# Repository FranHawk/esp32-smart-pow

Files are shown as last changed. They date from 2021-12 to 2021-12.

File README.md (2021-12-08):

# 前言

本文的目的是为了给将要制作的ESP32手环做技术储备

准备学习下ESP32，还有嵌入式GUI框架LVGL，通过做几个小项目练手是不错的选择，最终目标是做一个ESP32的手环

做一个ESP32手环任务量还是比较大的，涉及到很多新技术，我认为步子不能迈的太大容易翻车，决定先做一个ESP32的智能花盆

# 开源链接

**20211205 所有软硬件设计制作均已完成 资料开源至github**
**后续有时间还会发布一些小教程，可以在我的csdn上找到**

代码和外壳3D打印文件链接

[https://github.com/FranHawk/esp32-smart-pow](https://github.com/FranHawk/esp32-smart-pow)

GITHUB仓库结构
0.doc 相关文档
1.hardware pcb和3D打印所需资料
2.software  代码工程，有两个版本，gui版本可烧进任意ESP32或ESP32开发板，接屏幕和键盘即可，esp32-smart-pow为完成代码工程
3.simulator 存放lvgl的pc模拟器，用vs2019打开

PCB文件链接

[https://oshwhub.com/FranHawk/green-esp32/](https://oshwhub.com/FranHawk/green-esp32/)

视频演示链接

https://www.bilibili.com/video/BV11P4y137k2/

博客文档

https://blog.csdn.net/weixin_42487906/article/details/121779926

# 制作材料

元器件根据pcb工程里带的bom表买就可以了
pcb板嘉立创生产
电池买3.7V锂电池，容量随意
无线充电模块链接：https://item.taobao.com/item.htm?spm=a1z09.2.0.0.1bdb2e8dDijOkh&id=626465407103&_u=835dsdvlb35a
屏幕链接：https://item.taobao.com/item.htm?spm=a1z09.2.0.0.1bdb2e8dDijOkh&id=652101077844&_u=835dsdvl181e

外壳找淘宝3D打印

总成本大概100元左右，制作需要一些编程基础和网络信息搜索能力

## 开发平台

1.vs code+platformio ESP32开发

2.vs2019 lvgl模拟器 GUI界面设计与仿真

3.solidworks 2020 外壳设计

4.立创eda pcb设计

基本功能均已实现，还没发现更过BUG，如视频所示，但是软硬件还有需要进一步完善的地方，最近比较忙，等过了12月（202112）再进一步完善

# 功能

- 时间天气实时更新并显示
- 课程表，显示一周内的课程
- 电脑性能显示，通过局域网获取所使用的电脑当前的CPU内存等占用情况
- WIFI配网
- 亮度调节
- 蓝牙键盘，可作为一个蓝牙键盘控制电脑音量，ppt翻页，换歌等功能

# 功能展示



可以使用任意兼容QI标准的无线充电底座为其充电，市面上的充电底座几乎都可以



主界面显示天气时间温湿度，并且有利用lvgl8.1的gif解码器，有动图效果



天气界面



课程表界面



电脑性能监控界面



WIFI配网界面(功能和界面有待完善)



亮度调节界面



蓝牙键盘界面

**界面间通过一个滚动菜单选择**，可以使用模拟器模拟界面

下面是项目之初(20210920)写的需求分析和设计文档

# 需求分析

智能花盆所需要实现的功能如下：

- 基本花盆的功能：下端有透气孔，可以承载一株多肉植物，形状：长宽65mm正方形，高度根据实际情况调整的白色花盆，尽量保证外形的美观
- 带锂电池，无线充电模块，可以通过type-c口或者无线充电口为电池充电，同时为花盆供电。在无外部电源的时候，可以通过电池为花盆供电
- 板载USB转串口芯片，便于烧写代码
- 板载SD卡插槽，用户可将信息文件放入SD卡，ESP32可以读取
- ESP32 通过wifi功能，通过网络获取天气，时间等信息，通过局域网获取电脑性能等信息，后期可考虑加入wifi配网功能
- 通过一块1.54寸 240*240分辨率显示信息，信息如下，每一行代表一个页面
  	1. 当天时间和当天基本天气信息显示光照信息，检测当前是否充电，带**罗小黑动画效**果，通过晃动花盆可以切换动画效果
       2. 三天基本天气信息
       3. 电脑性能，内存占用等信息
       4. 课程表，显示当天课程
       5. 课程表，显示明天课程
       6. 显示当前植物信息

# 技术分析

- 首先硬件方面需要原理图PCB绘制和制作3D打印外壳技术，原理图PCB绘制采用立创EDA，外壳3D建模采用SW2020，去淘宝找厂家3D打印外壳 

  技能掌握情况：基本掌握

- 软件方面采用基于arduino的ESP32+LVGL框架，学习ESP32+LVGL基本使用，同时需要学习并移植XTRACK的页面生命周期管理API，根据需求分析需要掌握技术：LVGL移植到ESP32，ESP32连接到网络获取天气等信息，ESP32获取MPU6050数据，ESP32获取光敏电阻数据，LVGL文件系统移植，通过文件系统获取SD卡中信息，LVGL显示中文显示图片...

  20211002 基本掌握

## 任务细分

- 原理图和PCB绘制，投板制版并测试

  20210903 完成原理图和PCB绘制，已经投板，还未进入焊接阶段

  20210910 所有原件均到货，完成PCB制作，并完成测试，CH340不应该用5V供电，MPU6050少接一个电容工作不正常，其他部分工作正常，排线接口位置别扭，现有板子暂时能用，但是还是要再投一版

  20210915 新版本pcb投板并制作完成，测试完毕

  **已完成**

- 外壳设计与制作

  20210911 完成外壳设计工作

  20211120 完成外壳3D打印

  **已完成**

- 无线充电底座购买和无线充电模块测试

  20210910 无线充电底座到货，现有无线接收模块谐振频率不对，电压达不到5V，准备购买兼容QI协议的无线接收模块
  20211110 无线接收模块测试完毕
  **已达成**

- LVGL移植到ESP32

  20210817 完成LVGL移植

  **已达成**

- ESP32连接网络，获取天气，时间信息

  20210829 实现通过网络获取天气信息

  20210911 实现通过网络获取时间信息

  **已达成**

- ESP32连接网络，获取电脑性能信息

  20210825 实现通过网络获取电脑性能信息

  **已达成**

- ESP32获取MPU6050和光敏电阻的数据

  20210823 完成MPU6050数据获取

- ESP32上SD卡操作与LVGL文件系统移植

  20210830 完成SD卡操作与LVGL文件系统移植

  **已达成**

- LVGL中文和图片显示

  20210906 完成LVGL中文和图片显示

  **已达成**

- LVGL的PC模拟器使用

  20210906 初步完成LVGL的PC模拟器使用

  **已达成**

- LVGL移植XTRACK的页面生命周期管理API

  2021821 完成页面生命周期管理API学习，还未完成移植

  20210910 完成PC模拟器上菜单选择界面UI设计，发现XTRACK的页面生命周期管理暂时还用不到，先用纯LVGL开发

  **已达成**

- LVGL的PC模拟器设计UI交互页面

  20210910 完成PC模拟器上菜单选择界面UI设计，接下来完成子页面的设计

  20211120 完成所有子页面设计

  **已达成**

- UI交互页面移植到ESP32上，系统联调

  20211125 完成

  **已达成**

- ESP32上LVGL按键输入功能移植

  20210907 完成ESP32上LVGL按键输入功能移植

  **已达成**

# 硬件架构设计



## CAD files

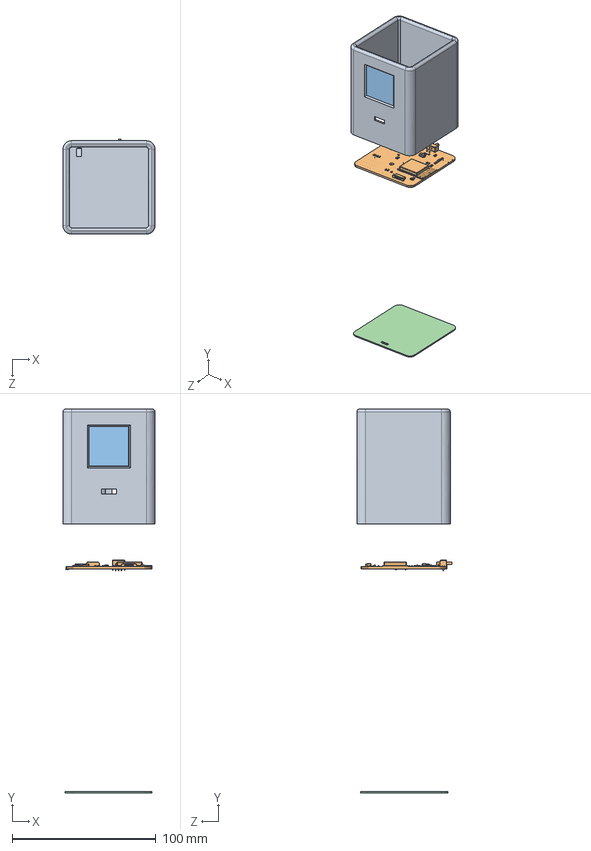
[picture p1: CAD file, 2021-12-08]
1.hardware/外壳文件/asm.SLDASM
64.0 x 266.8 x 66.3 mm
3D_PCB_PCB_green-esp32_2021-09-11_2021-09-11
1.54tft
bottom

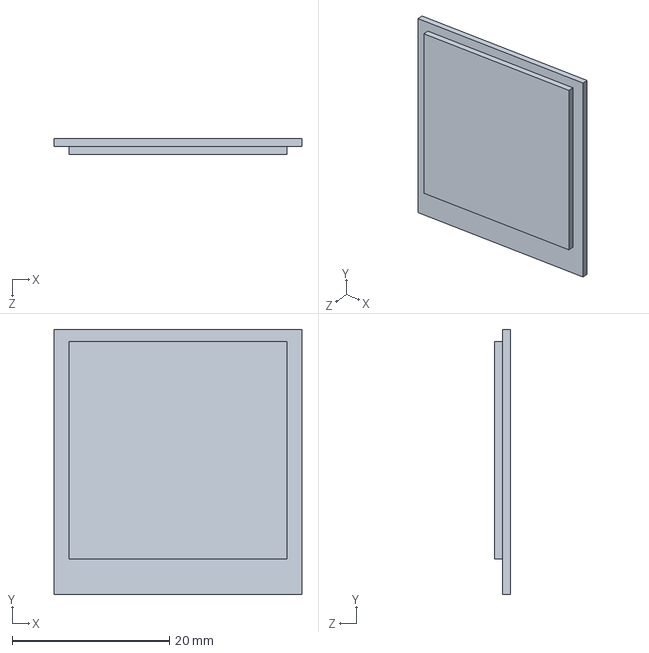
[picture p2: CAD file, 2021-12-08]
1.hardware/外壳文件/1.54tft.SLDPRT
31.5 x 33.7 x 2.00 mm

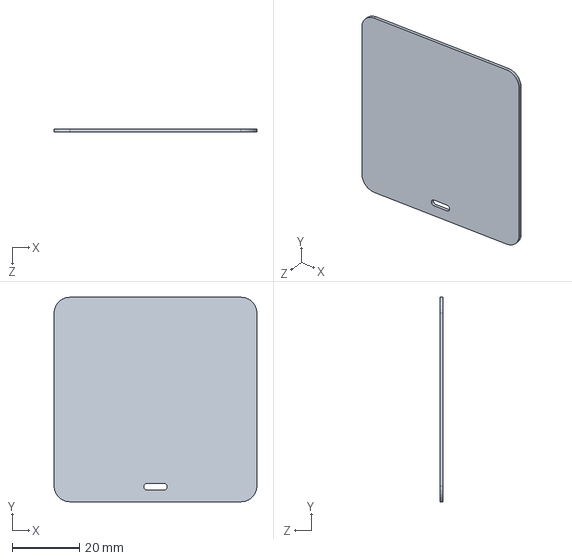
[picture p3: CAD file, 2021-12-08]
1.hardware/外壳文件/bottom.SLDPRT
60.5 x 61.0 x 1.00 mm

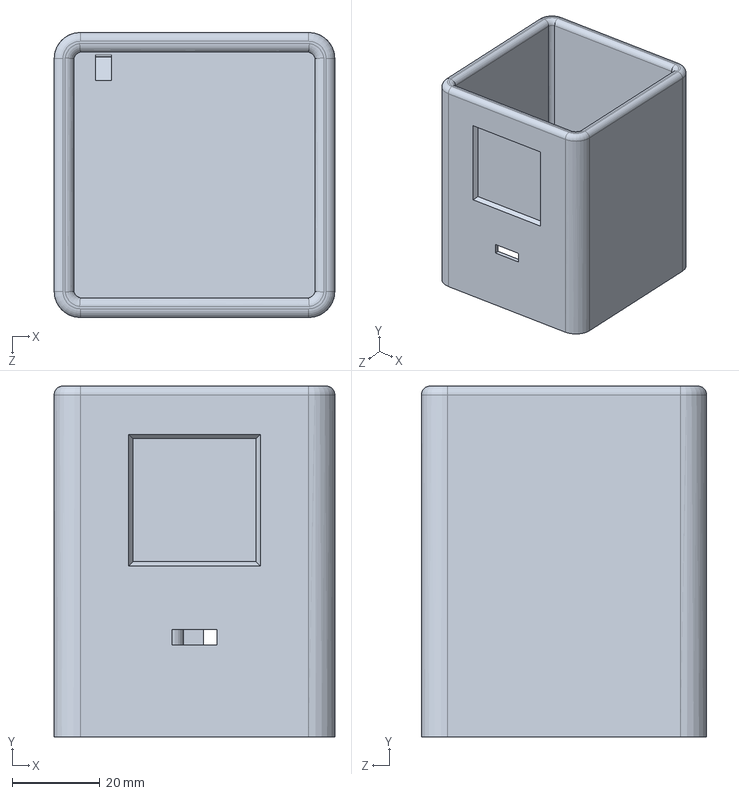
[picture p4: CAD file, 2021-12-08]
1.hardware/外壳文件/shell_1.SLDPRT
64.0 x 80.0 x 65.0 mm

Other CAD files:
1.hardware/外壳文件/bottom.STL
1.hardware/外壳文件/shell_1.STL

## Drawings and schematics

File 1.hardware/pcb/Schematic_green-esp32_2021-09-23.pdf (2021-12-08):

电源及锂电池充电 | USB转串口 | SD卡插槽

## 改为3.3V供电，V3接入3.3V

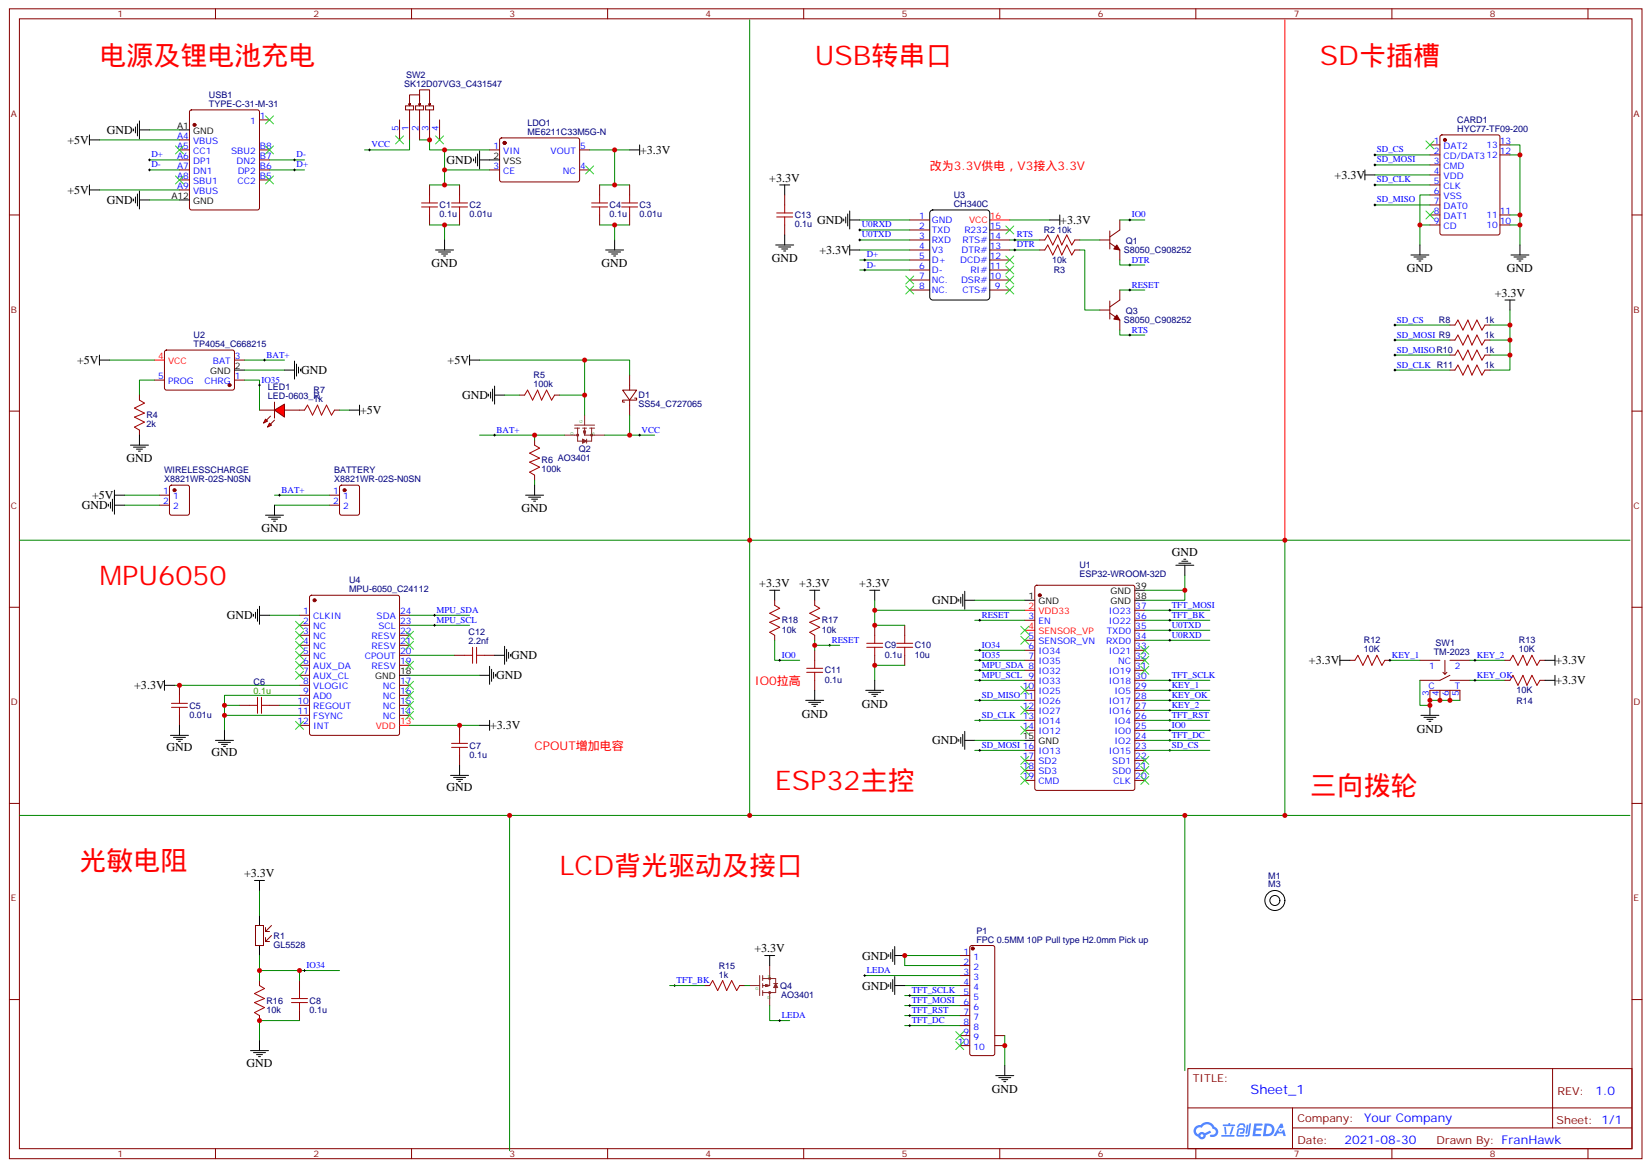
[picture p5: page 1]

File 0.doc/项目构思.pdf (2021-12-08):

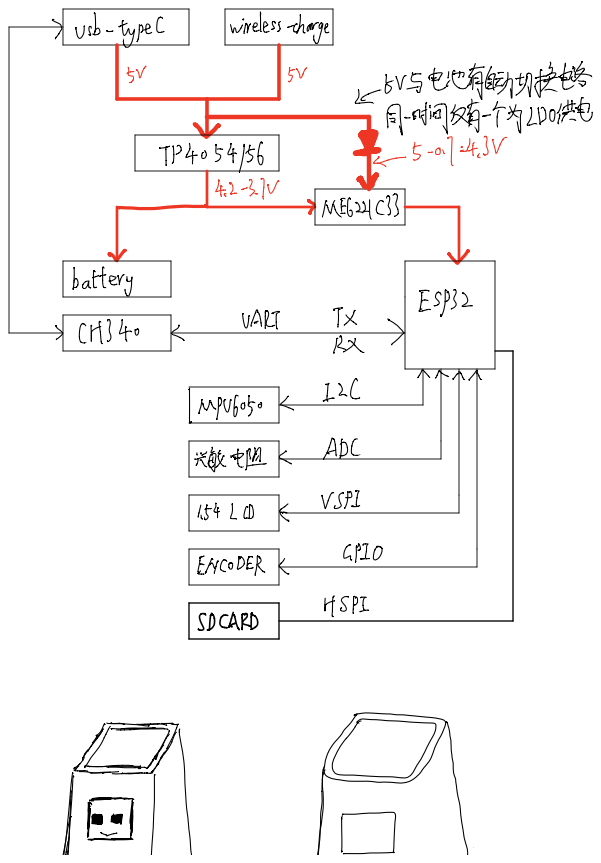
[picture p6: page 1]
sub typeC; wireless_charge; 5⽇电也有⾃动切换电路; 同时间仅有⼀个加⁰供电; battery; VAN; ESP32; CHI40 ⼈; MMof; VSPI; ENCODER; GPIO; SDCARD; HSPI

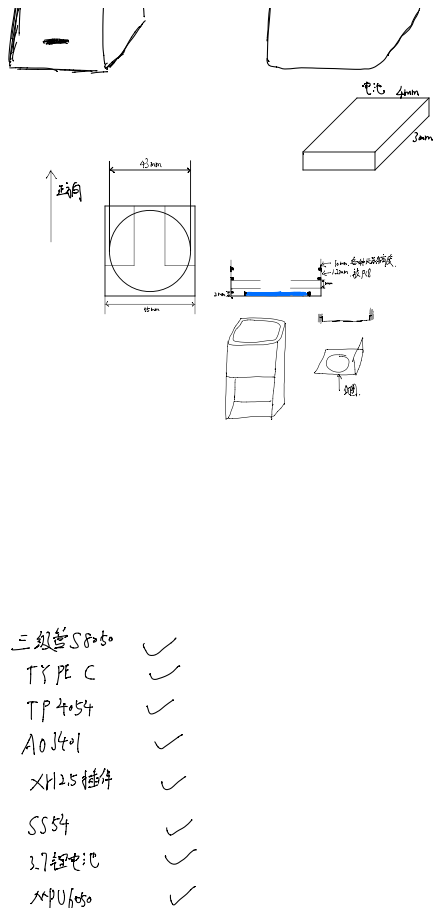
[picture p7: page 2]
mm齉 ⼀; 懿 iii LOO 䵼 - 鶴 国 靥; 三级営58050; TYPE C; TP⁴⁰⁵⁴; A⁰¹⁴⁰¹; 3.7锂电池 州⼉的

1 6

## 三挡拨轮

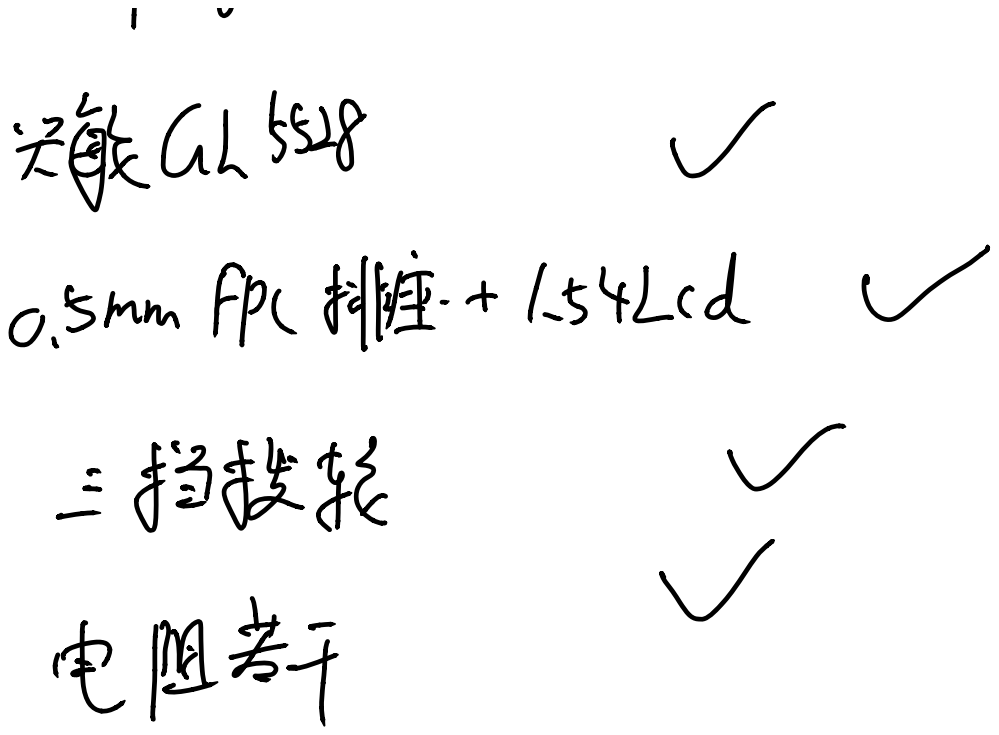
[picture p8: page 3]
以⁵⁵²⁸; o5mm欣排座 1.54Led it; 电阻轩

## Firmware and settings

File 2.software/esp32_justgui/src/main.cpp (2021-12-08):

#include <Arduino.h>
#include <lvgl.h>
#include <TFT_eSPI.h>
#include "sd_card.h"
#include "lv_port_indev.h"
#include "lv_port_fatfs.h"
#include "display.h"
#include "sence_1.h"
#include "lv_page_common.h"

// #include "lv_home_page.h"
// #include "lv_scroll_page.h"
// #include "lv_weather_page.h"
// #include "lv_class_page.h"
// #include "lv_pc_state_page.h"
// #include "lv_wifi_page.h"
// #include "lv_brightness_page.h"

SdCard tf;
Display screen;

void setup()
{
    Serial.begin(115200); /* prepare for possible serial debug */

    screen.init();
    screen.setBackLight(0.5);
    lv_port_indev_init();

    // tf.init();
    // lv_fs_if_init();   

    lv_app_load_home_scr();
    // lv_app_scroll();
    // lv_app_load_weather_scr();
    // lv_app_load_class_scr();
    // lv_app_load_pc_state_scr();
    // lv_app_load_wifi_scr();
    // lv_app_load_light_scr();
}

void loop()
{
    screen.routine(); /* let the GUI do its work */
    delay(5);
}

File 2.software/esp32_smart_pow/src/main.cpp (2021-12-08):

#include <Arduino.h>
#include <lvgl.h>
#include <TFT_eSPI.h>
#include "sd_card.h"
#include "lv_port_indev.h"
#include "lv_port_fatfs.h"
#include "display.h"
#include "lv_page_common.h"

#include <WiFi.h>
#include <time.h>

const char *ssid = "master";
const char *password = "guojiwutai";

const char* ntpServer = "pool.ntp.org";
const long  gmtOffset_sec = 8*3600; 
const int   daylightOffset_sec = 8*3600;

SdCard tf;
Display screen;

float g_screen_brightness = 0.4;

void setup()
{
    Serial.begin(115200); /* prepare for possible serial debug */

    WiFi.begin(ssid, password);
    while (WiFi.status() != WL_CONNECTED)
    {
        delay(500);
        Serial.print(".");
    }

    Serial.println("");
    Serial.println("WiFi connected");
    Serial.println("IP address: ");
    Serial.println(WiFi.localIP());

    configTime(gmtOffset_sec, daylightOffset_sec, ntpServer);
    lv_app_weather_update();
    
     
    screen.init();
    screen.setBackLight(g_screen_brightness);
    
    lv_port_indev_init();

    // tf.init();
    // lv_fs_if_init();   

    lv_app_load_home_scr();
    // lv_app_scroll();
    // lv_app_load_weather_scr();
    // lv_app_load_class_scr();
    // lv_app_load_pc_state_scr();
    // lv_app_load_wifi_scr();
    // lv_app_load_light_scr();
}

void loop()
{
    screen.routine(); /* let the GUI do its work */
    delay(5);
}

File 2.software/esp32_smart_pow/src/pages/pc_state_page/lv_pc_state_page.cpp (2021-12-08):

#include "lv_page_common.h"
#include <WiFi.h>

lv_timer_t *timer_pcstate;

static const char *host = "192.168.1.101";

static void lv_pc_state_update(lv_obj_t* pc_state_scr)
{
    WiFiClient client;

    if (!client.connect(host, 80,200))
    {
        Serial.println("Connect host failed!");
        return;
    }

    String getUrl = "/sse";
    client.print(String("GET ") + getUrl + " HTTP/1.1\r\n" + "Content-Type=application/json;charset=utf-8\r\n" + "Host: " + host + "\r\n" + "User-Agent=ESP32\r\n" + "Connection: close\r\n\r\n");
    Serial.println("Get send");

    delay(10);

    char endOfHeaders[] = "\n\n";
    bool ok = client.find(endOfHeaders);
    if (!ok)
    {
        Serial.println("No response or invalid response!");
    }
    Serial.println("here");
    String line = "";

    line += client.readStringUntil('\n');

    Serial.println(line);

    int16_t dataStart = 0;
    int16_t dataEnd = 0;
    String dataStr;

    lv_obj_t* pc_usage_arc = lv_obj_get_child(pc_state_scr,1);
    char cpuUsage[] = "CPU Usage";
    dataStart = line.indexOf(cpuUsage) + strlen(cpuUsage);
    dataEnd = line.indexOf("%", dataStart);
    dataStr = line.substring(dataStart, dataEnd);
    lv_arc_set_value(pc_usage_arc,dataStr.toInt());

    Serial.println("here1");

    lv_obj_t* ram_usage_arc = lv_obj_get_child(pc_state_scr,2);
    char ramUsage[] = "RAM Usage";
    dataStart = line.indexOf(ramUsage) + strlen(ramUsage);
    dataEnd = line.indexOf("%", dataStart);
    dataStr = line.substring(dataStart, dataEnd);
    lv_arc_set_value(ram_usage_arc,dataStr.toInt());

    Serial.println(dataStr.toInt());

    lv_obj_t* cpu_temp_label = lv_obj_get_child(pc_state_scr,4);
    char cpuTemp[] = "CPU Temp";
    dataStart = line.indexOf(cpuTemp) + strlen(cpuTemp);
    dataEnd = line.indexOf("c", dataStart);
    dataStr = line.substring(dataStart, dataEnd);
    lv_label_set_text_fmt(cpu_temp_label, "TEMP %s°C",dataStr.c_str());

    Serial.println("here3");

    lv_obj_t* cpu_freq_label = lv_obj_get_child(pc_state_scr,5);
    char cpuFreq[] = "CPU Frequency";
    dataStart = line.indexOf(cpuFreq) + strlen(cpuFreq);
    dataEnd = line.indexOf("GHz", dataStart);
    dataStr = line.substring(dataStart, dataEnd);
    lv_label_set_text_fmt(cpu_freq_label, "FREQ %sGHz",dataStr.c_str());

    Serial.println("here4");

    lv_obj_t* ram_used_label = lv_obj_get_child(pc_state_scr,7);
    char ramUsed[] = "RAM Used";
    dataStart = line.indexOf(ramUsed) + strlen(ramUsed);
    dataEnd = line.indexOf("GB", dataStart);
    dataStr = line.substring(dataStart, dataEnd);
    lv_label_set_text_fmt(ram_used_label, "USED %sG",dataStr.c_str());

    Serial.println("here5");

    lv_obj_t* ram_avaliable_label = lv_obj_get_child(pc_state_scr,8);
    char ramAvail[] = "RAM Aval";
    dataStart = line.indexOf(ramAvail) + strlen(ramAvail);
    dataEnd = line.indexOf("GB", dataStart);
    dataStr = line.substring(dataStart, dataEnd);
    lv_label_set_text_fmt(ram_avaliable_label, "AVAL %sG",dataStr.c_str());

    Serial.println("here6");

    lv_obj_t* vram_used_label = lv_obj_get_child(pc_state_scr,10);
    char gpuUsed[] = "GPU Used";
    dataStart = line.indexOf(gpuUsed) + strlen(gpuUsed);
    dataEnd = line.indexOf("GB", dataStart);
    dataStr = line.substring(dataStart, dataEnd);
    lv_label_set_text_fmt(vram_used_label, "VRAM %sG/4G",dataStr.c_str());

    Serial.println("here7");

    lv_obj_t* gpu_freq_label = lv_obj_get_child(pc_state_scr,11);
    char gpuFreq[] = "GPU Frequency";
    dataStart = line.indexOf(gpuFreq) + strlen(gpuFreq);
    dataEnd = line.indexOf("GHz", dataStart);
    dataStr = line.substring(dataStart, dataEnd);
    lv_label_set_text_fmt(gpu_freq_label, "FREQ %sGHz",dataStr.c_str());

    Serial.println("here8");

    lv_obj_t* fps_label = lv_obj_get_child(pc_state_scr,12);
    char fps[] = "FPS";
    dataStart = line.indexOf(fps) + strlen(fps);
    dataEnd = line.indexOf("Hz", dataStart);
    dataStr = line.substring(dataStart, dataEnd);
    lv_label_set_text_fmt(fps_label, "FPS %s",dataStr.c_str());

    Serial.println("here9");

    lv_obj_t* upload_label = lv_obj_get_child(pc_state_scr,13);
    Serial.println("here11");
    char upload[] = "UPLOAD ";
    dataStart = line.indexOf(upload) + strlen(upload);
    dataEnd = line.indexOf("MB/s", dataStart);
    dataStr = line.substring(dataStart, dataEnd);
    Serial.println("here12");
    Serial.println(dataStr.c_str());
    lv_label_set_text_fmt(upload_label,"> %sMB/s",dataStr.c_str());

    Serial.println("here10");

    lv_obj_t* download_label = lv_obj_get_child(pc_state_scr,14);
    char download[] = "DOWNLOAD ";
    dataStart = line.indexOf(download) + strlen(download);
    dataEnd = line.indexOf("MB/s", dataStart);
    dataStr = line.substring(dataStart, dataEnd);
    lv_label_set_text_fmt(download_label,"< %sMB/s",dataStr.c_str());

    client.stop();
}

static void lv_timer_time_update(lv_timer_t *timer)
{
    Serial.println("hello");
    if (timer->user_data != NULL)
    {
        lv_obj_t *pc_state_scr = (lv_obj_t *)timer->user_data;
        lv_pc_state_update(pc_state_scr);
    }
}

static void lv_timer_time_stop(void)
{
    Serial.println("time");
    lv_timer_del(timer_pcstate);
}

static void pc_usage_arc_value_change_cb(lv_event_t* e)
{
    lv_obj_t* arc = lv_event_get_target(e);
    lv_obj_t* label = (lv_obj_t*)lv_event_get_user_data(e);

    lv_label_set_text_fmt(label, "CPU %d%%", lv_arc_get_value(arc));
    lv_obj_align_to(label, arc, LV_ALIGN_CENTER, 0, 0);
}

static void ram_usage_arc_value_change_cb(lv_event_t* e)
{
    lv_obj_t* arc = lv_event_get_target(e);
    lv_obj_t* label = (lv_obj_t*)lv_event_get_user_data(e);

    lv_label_set_text_fmt(label, "RAM %d%%", lv_arc_get_value(arc));
    lv_obj_align_to(label, arc, LV_ALIGN_CENTER, 0, 0);
}
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

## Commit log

2021-12-08 修改readme文件
2021-12-08 修改个人信息
2021-12-12 增加 simulator
